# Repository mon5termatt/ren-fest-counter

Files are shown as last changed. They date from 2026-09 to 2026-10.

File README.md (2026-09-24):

# Ren Fest Counter

ESP32-WROOM-32 scoreboards for Renaissance festival games: a name on **8×** MAX7219 8×8 panels and a count on **4×** panels below, with local +/− buttons, a WiZ mote (ESP-NOW), and a SoftAP web UI.

```
  [======== NAME ========]   ← 8 modules (64×8)
  [==== NUMBER ====]         ← 4 modules (32×8), centered
        [ - ]  [ + ]
```

## Features

- Up to **8** scoreboards (compile-time `MAX_COUNTERS`), enable/disable in the web UI
- Each board: 12 FC-16 MAX7219 modules on one SPI chain (zones: name + number)
- Per-board physical **− / +** (debounce + hold-to-repeat); no hardware reset
- **WiZ mote** ESP-NOW remote with web-assignable key → action map
- SoftAP setup UI for names, counts, intensity, remote link, and keymap
- Settings persisted in NVS

## Hardware

### SPI / matrices

Shared `DIN` / `CLK` / **one CS** for the whole name+number daisy-chain. The display always shows the **active** (selected) counter; WiZ 1–4 switches which logical counter is shown.

| Signal | GPIO (default) |
|---|---|
| DIN | 19 |
| CLK | 18 |
| CS | 5 |

Power LED matrices from a solid **5 V** supply (not the ESP32 3V3 pin); share ground with the ESP32.

### Physical buttons

One − / + pair on the board adjusts the **active** counter:

| Button | GPIO |
|---|---|
| − | 26 |
| + | 14 |

Edit all pins in [`include/config.h`](include/config.h). Set unused CS/button entries to `-1`.

For more than ~4 boards you may run out of GPIOs; an I2C expander (e.g. MCP23017) is a later option.

## Build & flash

Requires [PlatformIO](https://platformio.org/).

```bash
pio run                    # build
pio run -e ota -t upload   # HTTP OTA over SoftAP Wi‑Fi (PC must be 192.168.4.x)
pio device monitor         # serial @ 115200
```

OTA uses **Wi‑Fi only** (`ota_host_ip.py` / SoftAP). Upload is an HTTP push to `http://192.168.4.1/update` (also available as a form on the web UI). Password for SoftAP: `renfest123`.

If the device doesn’t have `/update` yet (older build), one USB flash bootstraps it; after that use `-e ota` only.

## Web UI

On boot the ESP32 opens SoftAP:

- SSID: `RenFest-Counter`
- Password: `renfest123`
- URL: http://192.168.4.1/

There you can:

- Edit counter names / counts, enable boards, set LED intensity, blank/unblank
- **Reset counts** (only place that zeros a count — not on the remote or local buttons)
- Link a WiZ remote MAC (or clear to accept any)
- Assign each WiZ key to an action: `none`, `select` (counter N), `inc_active`, `dec_active`, `blank`, `unblank`

## WiZ mote (factory defaults)

Protocol matches WLED’s WiZ remote handler (`WizMoteMessageStructure`).

| Button | Default action |
|---|---|
| 1–4 | Select counter 1–4 |
| Bright + | Increment active |
| Bright − | Decrement active (floor 0) |
| ON | Unblank |
| OFF | Blank (counts kept) |
| NIGHT | Ignored |

Press a key on the remote once so it appears under “Last seen”, then **Link last seen** if you want to lock to that remote.

## Project layout

```
include/config.h       pins, MAX_COUNTERS, AP credentials
src/main.cpp
src/counters.*         state + NVS
src/display.*          MD_Parola zones
src/local_buttons.*    physical +/- 
src/wiz_remote.*       ESP-NOW receive
src/remote_map.*       key → action map
src/web_ui.*           SoftAP HTTP UI
```

## Notes

- ESP-NOW shares the SoftAP Wi-Fi channel (AP starts before ESP-NOW init).
- Module order: if text is mirrored or zones look swapped, check daisy-chain direction / `FC16_HW` vs your PCB variant in `display.cpp`.
- Count range: 0–9999.

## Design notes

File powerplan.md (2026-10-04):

# Ren Fest Counter — Power Plan

Rough runtime estimates for battery operation at a festival day
(**~10 am–9 pm ≈ 11 hours** continuous).

## Measured draws (5 V)

| Condition | Current |
|---|---|
| One half, min brightness | 0.2 A |
| Full setup, min brightness | ~0.4 A (estimated 2× half) |
| Full setup, full brightness (normal content) | 1.1 A |
| Checkerboard test, full bright | 2.0 A |
| All LEDs on, full bright | 3.1 A |

ESP32 / Wi‑Fi overhead is included in these meter readings.

## Power banks

Capacity labels are at **~3.7 V cell** voltage. Usable energy at **5 V USB**
after boost (~85% efficient):

| Bank | Label | Cell energy | ≈ Usable at 5 V |
|---|---|---|---|
| Small | 9000 mAh | ~33 Wh | ~5.6 Ah |
| Baseus Amblight | 30 000 mAh 65 W | **111 Wh** (rated) | ~18.9 Ah |

111 Wh = 30 000 mAh × 3.7 V — same figure the pack claims. At 5 V with ~85%
boost: `111 × 0.85 / 5 ≈ 18.9 Ah`.

[Baseus Amblight 65W 30000mAh](https://www.baseus.com/products/amblight-power-bank-65w-30000mah)

## Runtime estimates

| Load | 9000 mAh | One 30 K (111 Wh) | Two 30 K (sequential) |
|---|---|---|---|
| Full setup, min (0.4 A) | ~14 h | ~47 h | ~94 h |
| Full setup, high (1.1 A) | ~5 h | ~17 h | ~34 h |
| Checkerboard 2.0 A | ~2.8 h | ~9.5 h | ~19 h |
| All-on 3.1 A | ~1.8 h | ~6 h | ~12 h |

Naive “mAh ÷ mA” without the 3.7→5 V conversion overstates runtime by ~1.5–1.6×.

## Festival day (10 am–9 pm)

**11 hours** on one 30 000 mAh bank:

| Brightness | ~Draw | Used in 11 h | Headroom on one 30 K |
|---|---|---|---|
| Min | 0.4 A | ~4.4 Ah | Plenty (~¼ of bank) |
| Medium | 0.8 A | ~8.8 Ah | Comfortable (~½) |
| High | 1.1 A | ~12 Ah | OK (~⅔) |
| All-on stress | 3.1 A | ~34 Ah | **Not viable** on one bank |

## Recommended kit

- **Two Baseus 30 000 mAh** banks on hand.
- **Bank A** — counter only (dedicated cable; don’t share with phone).
- **Bank B** — phone + spare / overnight top-up.

A full phone charge is roughly **10–20 Wh** (~2–4 Ah at 5 V). Bank B can
refill a phone several times and still leave reserve.

## Tips

- Prefer **min–medium brightness** outdoors only as needed; blank/night mode
  when idle.
- Avoid long **all-on / full-bright** test patterns on battery.
- Use a short, thick USB cable; thin cables drop voltage at 1 A+.
- Watch the bank’s overload cutoff if something spikes near 3 A.
- Top up overnight between fest days if running high brightness all day.

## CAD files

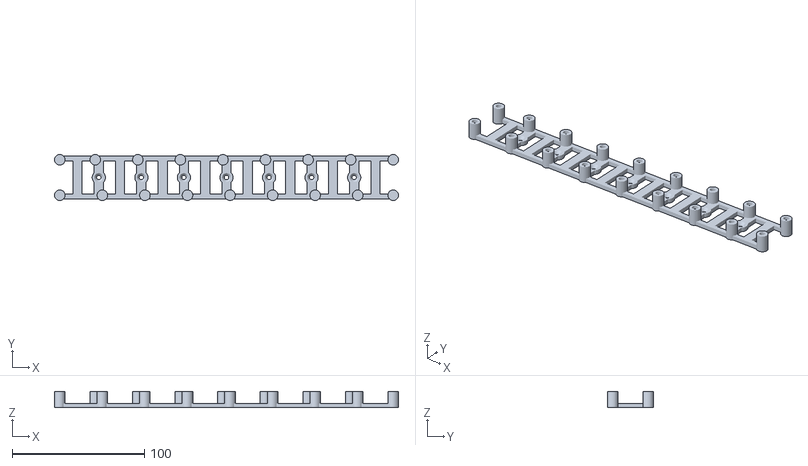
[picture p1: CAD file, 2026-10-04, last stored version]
LED_matrix_revA.stl
259.8 x 34.8 x 12.2

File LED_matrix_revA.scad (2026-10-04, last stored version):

// 8x8 LED matrix mounting frame
// http://www.thingiverse.com/thing:1883325
// Printbus, December 2016
//
// This consists of a mounting frame for 32mm 8x8 LED matrix modules.  
// Revision A adds flexibility that simplifies support for a handful of LED driver
// board types.  Types known to be supported are the FriedCircuits LED Matrix Link v1.2, 
// the printbus/klunkerbus LED Matrix Link v2.0, the board type with a MAXIM MAX7219
// located outside the LED matrix component, and the FC-16 type of driver board.  
// Sample parameters are provided for these boards types.
// 
// The top-level geometry should be tailored for the desired number of modules
// in the x-axis and the number of modules in the y-axis. For reinforcement in long, 
// thin displays, the top level geometry provides for enabling reinforcement struts
// to the x-axis for the inner rows of modules.
//
// For OpenSCAD documentation, see 
// http://en.wikibooks.org/wiki/OpenSCAD_User_Manual/The_OpenSCAD_Language
//
// NOTE ON BOARD ORIENTATIONS: The ability to properly drive pixels throughout an array 
// of modules depends on the board design, board orientation, the software driving the
// display, and the orientation of the LED matrix on the board.  Experimenting with
// a couple of LED modules before finalizing, printing, and assembling/wiring a
// display panel is suggested. 
//
// NOTE ON BOARD DIMENSIONS: The LED matrix components are typically undersized
// slightly less than 32mm. This allows adjacent LED matrices to be spaced at exact
// 32mm intervals so that all LED rows/columns in a large display are equally spaced.
// All of the driver boards sampled, however, have been found to be slightly oversized.
// Although the oversize may be small, it can accumulate and create fit problems for 
// display panels that use a multiple number of adjacent driver boards.  
// The sample dimensions provided here reflect the oversize dimensions measured on
// a small sample of board.  Check the dimensions of your boards for compatibility.
// Note that dimensions may vary across identical boards - don't assume all boards
// will have the same exact dimensions. Adjust the board dimension parameters here
// to accomodate the largest board that will be used.  If there is a concern that
// the oversize boards may lead to undesirable gaps between LED matrices, file the
// board edges as required to allow 32mm intervals and adjust the board dimension
// parameter(s) here accordingly.  
//
// NOTE ON MOUNTING SCREW SIZING: There are multiple factors to consider in choosing the 
// size of screws for mounting driver boards to the printed frame.  1) The amount
// of corner post material provided at each mounting screw location is limited by 
// the space between the board edges and the mounting holes. Using a smaller 
// screw size will increase the corner post wall thickness and provide more strength.  
// 2) Going with a smaller diameter screw provides tolerance in hole placements
// and board alignment.  3) Most boards provide only limited clearance for the
// heads of mounting screws.  A smaller diameter screw will have a smaller
// diameter head.  

// NOTE ON LED MATRIX ALIGNMENT: Sloppy alignment of the LED matrices on the boards can lead to 
// a sloppy looking display panel.   Soldering the LED SIP sockets to the board while 
// the LED matrix is plugged into the SIP sockets is suggested.  
//
// NOTES ON PANEL ASSEMBLY: Especially for larger display panels, measure received 
// driver boards for compatibility with the dimension parameters for the frame design. 
// File or sand material from board edges if boards are excessively oversized.
// Burrs or any other protrusions should be cleaned from the driver boards before 
// mounting them onto the frame.    Install all modules with hardware left initially
// loose, and tighten the hardware after adjusting boards for any alignment issues.
// If multiple smaller frames are used to form a larger display, clean any printing
// burrs from the frame sides that mate.  Zip ties might be adequate in holding partial 
// frames together. 
//
////////// REVISION HISTORY ///////////////////////////////////////////////////
// YYMMDD date code
// 161110 - initial publish
// 161203 - Revision A, improved support for additional board types

////////// INCLUDE AND USE  ///////////////////////////////////////////////////
// NOTE: openSCAD version 2014.03 or newer recommended

////////// TOP LEVEL GEOMETRY  ////////////////////////////////////////////////
// Array size and options are set in PARAMETERS below (x_count, y_count, strut)
frame( x_count=x_count, y_count=y_count, strut=strut );

////////// PARAMETERS  ////////////////////////////////////////////////////////
// All dimensions are millimeter
// Open Window > Customizer to edit these as UI controls

/* [Frame] */
// Number of LED modules in the x-axis
x_count = 8;
// Number of LED modules in the y-axis
y_count = 2;
// X-axis reinforcement struts between y-axis rows
strut = false;

/* [LED Posts] */
// Fastener type in corner posts
post_fastener = "heatset"; // [heatset:M3 heat-set insert, thread:M3 direct thread (self-tap)]
// Which corners get screw posts
post_mode = "skip"; // [diagonal:Diagonal (FL+RR), every_other:Every other column, skip:Skip X (outer of group)]
// Skip mode: physical board width in modules (e.g. 4 for 4-wide FC-16 style)
post_group_x = 4; // [1:16]
// Skip mode: physical board height in modules
post_group_y = 1; // [1:8]
// Skip mode: which side to keep at board-board seams (holes are too close for both)
post_seam = "keep_right"; // [keep_right:Keep right (skip next board left), keep_left:Keep left (skip prev board right)]
// Heat-set: recommended hole ID for typical M3 brass inserts (mm)
post_insert_id = 4.0;
// Heat-set: insert length / blind hole depth (mm)
post_insert_depth = 5.0;
// Heat-set: minimum post OD for wall strength around the insert (mm)
post_od_min = 8.0;
// Direct thread: hole ID for M3 self-tap into plastic (nominal 2.7 + print fit)
post_thread_id = 2.9;
// Fragment count for round posts and holes
fn_circle = 64; // [16:128]

/* [Panel Mount] */
// Enable frame-to-board mounting holes between modules
panel_mount = true;
// Clearance hole ID — M3 standard fit (mm)
mnt_hid = 3.3;
// Countersink OD at frame front (mm)
mnt_cs_od = 6.5;
// Countersink depth (mm)
mnt_cs_depth = 2.0;
// Circular pad OD at each mount point (mm)
mnt_pad_od = 10;

/* [Hidden] */
// Board Reference Dimensions (as measured)
// Sample measurements are provided for various module types
// Only one block of measurements should be uncommented - all others need to be commented out
// Tailor the measurements for your board type if your measurements differ
// -------- dimensions for Friedcircuits LED Matrix Link v1.2 and LED Matrix Master v1.2
// For Friedcircuits v1.2, see https://friedcircuits.us/
// Note that Friedcircuits hole spacing leaves limited room for screw heads
// If using right angle headers to interconnect boards, consider soldering them after mounting boards
//   This will help minimize header placement from affecting board spacing
/*  ( a /* here comments out this block, a //* will uncomment it )
bd_sx = 32.2;       // board size in x-axis for the LED module
bd_sy = 32.25;      // board size in y-axis for the LED module
bd_hspx = 27.8;     // board hole spacing in x-axis, center to center
bd_hspy = 27.8;     // board hole spacing in y-axis, center to center
bd_hid = 3.3;       // board hole inner diameter (not used, but included for reference)
bd_pin_len = 0;     // pcb pin length in area of I-frame strut (n/a for low if_strut_w values)
//*/

// -------- dimensions for LED Matrix Link, klunkerbus v2.0
// For klunkerbus v2.0, see https://oshpark.com/shared_projects/J1PUJCGP
// If using right angle headers to interconnect boards, consider soldering them after mounting boards
//   This will help minimize header placement from affecting board spacing
//*  ( a /* here comments out this block, a //* will uncomment it )
bd_sx = 32.15;      // board size in x-axis for the LED module
bd_sy = 32.15;      // board size in y-axis for the LED module
bd_hspx = 26.8;     // board hole spacing in x-axis, center to center
bd_hspy = 26.8;     // board hole spacing in y-axis, center to center
bd_hid = 3.3;       // board hole inner diameter (not used, but included for reference)
bd_pin_len = 0;     // pcb pin length in area of I-frame strut (n/a for low if_strut_w values)
//*/
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

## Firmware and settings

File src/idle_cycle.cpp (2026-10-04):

#include "idle_cycle.h"
#include "config.h"
#include "counters.h"
#include "display.h"
#include "setup_menu.h"

namespace {
  uint32_t lastActivityMs = 0;
  uint32_t lastCycleMs = 0;
  bool cycling = false;
  bool idleOwnsScroller = false;
  bool waitScrollerPass = false;  // hold until marquee finishes one pass (if scrolling)
  uint8_t playlistCursor = 0;  // next step to show
  uint8_t msgCursor = 0;       // next auto message index
  uint8_t cntCursor = 0;       // next auto counter index
  uint8_t prevOut = 0;         // effectOut of the step currently on screen

  int8_t nextEnabled(uint8_t from) {
    for (uint8_t step = 1; step <= MAX_COUNTERS; step++) {
      uint8_t i = (from + step) % MAX_COUNTERS;
      if (Counters::isEnabled(i)) return static_cast<int8_t>(i);
    }
    return -1;
  }

  int8_t nextEnabledFrom(uint8_t from) {
    for (uint8_t step = 0; step < MAX_COUNTERS; step++) {
      uint8_t i = (from + step) % MAX_COUNTERS;
      if (Counters::isEnabled(i)) return static_cast<int8_t>(i);
    }
    return -1;
  }

  int8_t nextMessageFrom(uint8_t from) {
    const uint8_t n = Counters::scrollMessageCount();
    if (n == 0) return -1;
    for (uint8_t step = 0; step < n; step++) {
      uint8_t i = (from + step) % n;
      const char* msg = Counters::scrollMessage(i);
      if (msg && msg[0]) return static_cast<int8_t>(i);
    }
    return -1;
  }

  uint8_t enabledTotal() {
    return Counters::enabledCount();
  }

  bool anyNonEmptyMessage() {
    return nextMessageFrom(0) >= 0;
  }

  bool stepIsValid(const IdleStep& step) {
    if (step.kind == IdleCounter) {
      if (step.index == IdleAutoIndex) return enabledTotal() > 0;
      return Counters::isEnabled(step.index);
    }
    if (step.kind == IdleMessage) {
      if (step.index == IdleAutoIndex) return anyNonEmptyMessage();
      if (step.index >= Counters::scrollMessageCount()) return false;
      const char* msg = Counters::scrollMessage(step.index);
      return msg && msg[0];
    }
    return false;
  }

  int8_t nextValidPlaylistIndex(uint8_t from) {
    const uint8_t len = Counters::idlePlaylistLen();
    if (len == 0) return -1;
    for (uint8_t step = 0; step < len; step++) {
      uint8_t i = (from + step) % len;
      if (stepIsValid(Counters::idleStep(i))) return static_cast<int8_t>(i);
    }
    return -1;
  }

  void stopIdleScroller() {
    if (idleOwnsScroller) {
      idleOwnsScroller = false;
      waitScrollerPass = false;
      if (Display::scrollerActive()) {
        Display::stopManualScroller(false);
      }
    }
  }

  // out(prev) → in(next); caller stamps hold after this returns.
  bool showPlaylistStep(uint8_t idx) {
    IdleStep step = Counters::idleStep(idx);
    if (!stepIsValid(step)) return false;
    const uint8_t effectIn = step.effectIn;
    const uint8_t effectOut = step.effectOut;
    const uint8_t exitEff = prevOut;

    if (step.kind == IdleCounter) {
      uint8_t ci = step.index;
      if (ci == IdleAutoIndex) {
        int8_t n = nextEnabledFrom(cntCursor);
        if (n < 0) return false;
        ci = static_cast<uint8_t>(n);
        cntCursor = static_cast<uint8_t>((ci + 1) % MAX_COUNTERS);
      }
      // Don't hard-clear — snapshot must see current pixels for the out anim.
      if (idleOwnsScroller) {
        idleOwnsScroller = false;
        waitScrollerPass = false;
      }
      Display::animateDisplayedOff(exitEff);
      Counters::setActiveIndex(ci, false);
      Display::idleShowNext(Counters::getConst(ci).count, effectIn);
      prevOut = effectOut;
      return true;
    }

    // Message: startManualScroller snapshots + exit-animates with prevOut.
    uint8_t mi = step.index;
    if (mi == IdleAutoIndex) {
      int8_t n = nextMessageFrom(msgCursor);
      if (n < 0) return false;
      mi = static_cast<uint8_t>(n);
      const uint8_t msgN = Counters::scrollMessageCount();
      msgCursor = msgN ? static_cast<uint8_t>((mi + 1) % msgN) : 0;
    }
    idleOwnsScroller = false;
    waitScrollerPass = false;
    const char* msg = Counters::scrollMessage(mi);
    Display::startManualScroller(effectIn, msg, Counters::scrollMessageBottom(mi), exitEff);
    idleOwnsScroller = Display::scrollerActive();
    // Only wait for a full pass when text actually scrolls (fit-only).
    waitScrollerPass = idleOwnsScroller && !Display::scrollerCompletedPass();
    prevOut = effectOut;
    return true;
  }

  bool advanceLegacyCounters() {
    int8_t n = nextEnabled(Counters::activeIndex());
    if (n < 0) return false;
    if (idleOwnsScroller) {
      idleOwnsScroller = false;
      waitScrollerPass = false;
    }
    Display::animateDisplayedOff(prevOut);
    Counters::setActiveIndex(static_cast<uint8_t>(n), false);
    Display::idleShowNext(Counters::getConst(n).count, Counters::idleEffectIn());
    prevOut = Counters::idleEffectOut();
    return true;
  }

  bool advanceOnce() {
    const uint8_t len = Counters::idlePlaylistLen();
    if (len == 0) {
      return advanceLegacyCounters();
    }

    int8_t idx = nextValidPlaylistIndex(playlistCursor);
    if (idx < 0) return false;
    if (!showPlaylistStep(static_cast<uint8_t>(idx))) return false;
    playlistCursor = static_cast<uint8_t>((static_cast<uint8_t>(idx) + 1) % len);
    return true;
  }

  bool holdElapsed(uint32_t now) {
    // Scrolling messages: advance as soon as one full marquee pass finishes.
    if (waitScrollerPass) {
      if (Display::scrollerActive() && !Display::scrollerCompletedPass()) return false;
      waitScrollerPass = false;
      return true;
    }
    // Counters / static (fit) messages: hold for idle cycle seconds.
    const uint32_t holdMs = (uint32_t)Counters::idleCycleSeconds() * 1000UL;
    return (now - lastCycleMs) >= holdMs;
  }
}

namespace IdleCycle {

void begin() {
  lastActivityMs = millis();
  lastCycleMs = millis();
  cycling = false;
  idleOwnsScroller = false;
  waitScrollerPass = false;
  playlistCursor = 0;
  msgCursor = 0;
  cntCursor = 0;
  prevOut = Counters::idleEffectOut();
}

void noteActivity() {
  lastActivityMs = millis();
  if (cycling) {
    cycling = false;
    stopIdleScroller();
    Serial.println(F("[idle] activity — stop cycle"));
  }
}

bool isCycling() { return cycling; }

bool startNow() {
  const uint8_t plLen = Counters::idlePlaylistLen();
  if (plLen == 0 && enabledTotal() < 2) return false;
  if (plLen > 0 && nextValidPlaylistIndex(0) < 0) return false;
  if (Counters::blanked() && Counters::blankBrightnessPercent() == 0) return false;

  // Drop any idle-owned marquee before restarting from the top.
  stopIdleScroller();
  cycling = true;
  playlistCursor = 0;
  msgCursor = 0;
  cntCursor = 0;
  waitScrollerPass = false;
  prevOut = Counters::idleEffectOut();
  Serial.println(F("[idle] start now"));
  if (!advanceOnce()) {
    cycling = false;
    return false;
  }
  lastCycleMs = millis();
  lastActivityMs = millis();
  return true;
}

void loop() {
  if (SetupMenu::active()) return;

  if (Display::scrollerActive() && !idleOwnsScroller) {
    return;
  }

  const uint8_t plLen = Counters::idlePlaylistLen();
  if (plLen == 0 && enabledTotal() < 2) {
    cycling = false;
    return;
  }
  if (plLen > 0 && nextValidPlaylistIndex(0) < 0) {
    cycling = false;
    return;
  }

  if (Counters::blanked() && Counters::blankBrightnessPercent() == 0) {
    return;
  }

  const uint32_t now = millis();

  if (!cycling) {
    if (now - lastActivityMs >= (uint32_t)Counters::idleTimeoutSeconds() * 1000UL) {
      cycling = true;
      playlistCursor = 0;
      msgCursor = 0;
      cntCursor = 0;
      waitScrollerPass = false;
      prevOut = Counters::idleEffectOut();
      Serial.println(F("[idle] start cycle"));
      if (!advanceOnce()) {
        cycling = false;
      } else {
        // Hold starts after enter finishes (advanceOnce is blocking on anims).
        lastCycleMs = millis();
      }
    }
    return;
  }

  if (!holdElapsed(now)) return;

  if (!advanceOnce()) {
    cycling = false;
    stopIdleScroller();
  } else {
    lastCycleMs = millis();
  }
}

}  // namespace IdleCycle

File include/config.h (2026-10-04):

#pragma once

#include <Arduino.h>

// ---------------------------------------------------------------------------
// Single scoreboard: one CS daisy-chain (name panels + number panels).
// Remote 1–4 / web switches which logical counter is shown on that display.
// ---------------------------------------------------------------------------
static constexpr bool SINGLE_DISPLAY = true;

// Full build: NAME=8, NUMBER=4 on one daisy-chain.
static constexpr uint8_t MODULES_NAME = 8;
static constexpr uint8_t MODULES_NUMBER = 4;
static constexpr uint8_t MODULES_PER_BOARD = MODULES_NAME + MODULES_NUMBER;

// 8×2 frame: top (name) row is rotated 180° relative to the number row.
static constexpr bool NAME_ZONE_FLIP_UD = true;
static constexpr bool NAME_ZONE_FLIP_LR = true;

static constexpr uint8_t MAX_COUNTERS = 8;
static constexpr uint8_t NAME_MAX_LEN = 15;
static constexpr int32_t COUNT_MAX = 9999;

// ---------------------------------------------------------------------------
// SPI / MAX7219 — one CS for the whole name+number chain
// ---------------------------------------------------------------------------
#if defined(ARDUINO_XIAO_ESP32C3)
// XIAO ESP32C3 — SPI on D7/D8/D10 edge (D9 left free / BOOT); VCC/GND on their own pads
static constexpr uint8_t PIN_DIN = 10;     // D10
static constexpr uint8_t PIN_CLK = 8;      // D8
static constexpr int8_t PIN_CS = 20;       // D7
#else
// ESP32-WROOM-32 defaults
static constexpr uint8_t PIN_DIN = 19;
static constexpr uint8_t PIN_CLK = 18;
static constexpr int8_t PIN_CS = 5;
#endif

// Kept as arrays for compatibility; only [0] is used in SINGLE_DISPLAY mode.
static constexpr int8_t CS_PINS[MAX_COUNTERS] = {
  PIN_CS, -1, -1, -1, -1, -1, -1, -1
};

#include "wifi_config.h"

static constexpr uint8_t DEFAULT_INTENSITY = 4;
static constexpr uint8_t DEFAULT_ENABLED_COUNT = 4;  // slots 1–4 selectable out of the box
static constexpr uint8_t SCROLLER_MAX_LEN = 64;      // top marquee message
static constexpr uint8_t SCROLLER_BOTTOM_MAX_LEN = 16; // bottom line (number zone)
static constexpr uint8_t MAX_SCROLL_MESSAGES = 8;
static constexpr uint8_t MAX_IDLE_PLAYLIST = 16;

// ---------------------------------------------------------------------------
// Idle auto-cycle (single display)
// ---------------------------------------------------------------------------
static constexpr uint32_t IDLE_TIMEOUT_MS = 30000;  // start cycling after 30s idle
static constexpr uint32_t IDLE_CYCLE_MS = 5000;     // default; override via web UI idleCycleSeconds
static constexpr uint16_t DOUBLE_TAP_MS = 400;      // WiZ remote double-tap window

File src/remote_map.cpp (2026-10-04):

#include "remote_map.h"
#include "config.h"
#include "counters.h"
#include "display.h"
#include "idle_cycle.h"
#include "setup_menu.h"
#include "show_mode.h"
#include <Preferences.h>
#include <cstring>

namespace {
  Preferences prefs;

  constexpr uint8_t WIZ_ON = 1;
  constexpr uint8_t WIZ_OFF = 2;
  constexpr uint8_t WIZ_NIGHT = 3;
  constexpr uint8_t WIZ_BRIGHT_DOWN = 8;
  constexpr uint8_t WIZ_BRIGHT_UP = 9;
  constexpr uint8_t WIZ_ONE = 16;
  constexpr uint8_t WIZ_TWO = 17;
  constexpr uint8_t WIZ_THREE = 18;
  constexpr uint8_t WIZ_FOUR = 19;

  constexpr uint8_t KNOWN_BUTTONS[] = {
    WIZ_ON, WIZ_OFF, WIZ_NIGHT,
    WIZ_BRIGHT_DOWN, WIZ_BRIGHT_UP,
    WIZ_ONE, WIZ_TWO, WIZ_THREE, WIZ_FOUR
  };
  constexpr uint8_t KNOWN_COUNT = sizeof(KNOWN_BUTTONS) / sizeof(KNOWN_BUTTONS[0]);

  RemoteMap::Binding bindings[KNOWN_COUNT];

  // ON×3 then OFF×3 (≤1.5s between taps) opens setup.
  // First ON unblanks immediately; further taps only advance the combo.
  constexpr uint8_t COMBO_NEED = 3;
  constexpr uint32_t COMBO_GAP_MS = 1500;
  uint8_t comboOnCount = 0;
  uint8_t comboOffCount = 0;
  uint32_t comboLastMs = 0;
  bool comboActive = false;
  bool comboOnFired = false;  // first ON already ran UNBLANK

  void clearComboArm() {
    comboOnCount = 0;
    comboOffCount = 0;
    comboActive = false;
    comboOnFired = false;
  }

  int findIndex(uint8_t buttonId);  // defined below

  void execute(uint8_t action, uint8_t param, uint8_t effectIn, uint8_t effectOut,
               uint8_t speed);  // defined below

  void fireBindingIndex(int idx) {
    if (idx < 0 || idx >= static_cast<int>(KNOWN_COUNT)) return;
    const RemoteMap::Binding& b = bindings[idx];
    if (b.action != RemoteMap::ACTION_IDLE_START) {
      IdleCycle::noteActivity();
    }
    execute(b.action, b.param, b.effectIn, b.effectOut, b.speed);
  }

  int findIndex(uint8_t buttonId) {
    for (uint8_t i = 0; i < KNOWN_COUNT; i++) {
      if (bindings[i].buttonId == buttonId) return i;
    }
    return -1;
  }

  uint8_t clampEffect(uint8_t e) {
    return ShowMode::valid(e) ? e : ShowMode::LEFT;
  }

  uint8_t clampSpeed(uint8_t s) {
    if (s == 0) return 0;  // 0 = use anim-type default
    if (s > 20) return 20;
    return s;
  }

  void setDefault(uint8_t id, uint8_t act, uint8_t param,
                  uint8_t effectIn, uint8_t effectOut = ShowMode::LEFT,
                  uint8_t speed = 0) {
    for (uint8_t i = 0; i < KNOWN_COUNT; i++) {
      if (bindings[i].buttonId == id) {
        bindings[i].action = act;
        bindings[i].param = param;
        bindings[i].effectIn = effectIn;
        bindings[i].effectOut = effectOut;
        bindings[i].speed = speed;
        return;
      }
    }
  }

  void applyDefaults() {
    for (uint8_t i = 0; i < KNOWN_COUNT; i++) {
      bindings[i].buttonId = KNOWN_BUTTONS[i];
      bindings[i].action = RemoteMap::ACTION_NONE;
      bindings[i].param = 0;
      bindings[i].effectIn = ShowMode::LEFT;
      bindings[i].effectOut = ShowMode::LEFT;
      bindings[i].speed = 0;
    }

    setDefault(WIZ_ONE, RemoteMap::ACTION_SELECT, 0, ShowMode::LEFT, ShowMode::LEFT);
    setDefault(WIZ_TWO, RemoteMap::ACTION_SELECT, 1, ShowMode::LEFT, ShowMode::LEFT);
    setDefault(WIZ_THREE, RemoteMap::ACTION_SELECT, 2, ShowMode::LEFT, ShowMode::LEFT);
    setDefault(WIZ_FOUR, RemoteMap::ACTION_SELECT, 3, ShowMode::LEFT, ShowMode::LEFT);
    setDefault(WIZ_BRIGHT_UP, RemoteMap::ACTION_INC_ACTIVE, 0, ShowMode::UP, ShowMode::LEFT);
    setDefault(WIZ_BRIGHT_DOWN, RemoteMap::ACTION_DEC_ACTIVE, 0, ShowMode::DOWN, ShowMode::LEFT);
    setDefault(WIZ_ON, RemoteMap::ACTION_UNBLANK, 0, ShowMode::FREEZE, ShowMode::FREEZE);
    setDefault(WIZ_OFF, RemoteMap::ACTION_BLANK, 0, ShowMode::FREEZE, ShowMode::FREEZE);
    setDefault(WIZ_NIGHT, RemoteMap::ACTION_SCROLLER, 0, ShowMode::LEFT, ShowMode::LEFT);
  }

  void execute(uint8_t action, uint8_t param, uint8_t effectIn, uint8_t effectOut,
               uint8_t speed) {
    const uint8_t inEff = clampEffect(effectIn);
    const uint8_t outEff = clampEffect(effectOut);
    const uint8_t spd = clampSpeed(speed);

    if (action != RemoteMap::ACTION_SCROLLER && Display::scrollerActive()) {
      // Animate marquee off with this key's out, then continue the action.
      Display::animateDisplayedOff(outEff, spd);
      Display::stopManualScroller(action != RemoteMap::ACTION_SELECT);
    }

    switch (action) {
      case RemoteMap::ACTION_NONE:
        break;

      case RemoteMap::ACTION_SELECT:
        if (Counters::isEnabled(param)) {
          Counters::setActiveIndex(param);
          Display::selectShow(inEff, spd);
          Counters::saveIfDirty();
          Serial.printf("[wiz] select counter %u (%s) in %u out %u spd %u\n", param + 1,
                        Counters::getConst(param).name, inEff, outEff, spd);
        } else {
          Serial.printf("[wiz] select %u ignored (disabled)\n", param + 1);
        }
        break;

      case RemoteMap::ACTION_INC_ACTIVE: {
        uint8_t a = Counters::activeIndex();
        if (Counters::inc(a)) {
          Display::onCountIncreased(Counters::getConst(a).count, inEff, spd);
          Counters::saveIfDirty();
        }
        break;
      }

      case RemoteMap::ACTION_DEC_ACTIVE: {
        uint8_t a = Counters::activeIndex();
        if (Counters::dec(a)) {
          Display::onCountDecreased(Counters::getConst(a).count, inEff, spd);
          Counters::saveIfDirty();
        }
        break;
      }

      case RemoteMap::ACTION_BLANK:
        Counters::setBlanked(true);
        Display::applyBlanked();
        Counters::saveIfDirty();
        break;

      case RemoteMap::ACTION_UNBLANK:
        Counters::setBlanked(false);
        Display::applyBlanked();
        Counters::saveIfDirty();
        break;

      case RemoteMap::ACTION_SCROLLER:
        IdleCycle::noteActivity();
        if (Display::scrollerActive()) {
          Display::animateDisplayedOff(outEff, spd);
          Display::stopManualScroller();
          Serial.println(F("[wiz] scroller stop"));
        } else {
          Display::startManualScroller(inEff, nullptr, nullptr, outEff, spd);
          Serial.println(F("[wiz] scroller start"));
        }
        break;

      case RemoteMap::ACTION_IDLE_START:
        if (IdleCycle::isCycling()) {
          IdleCycle::noteActivity();
          Serial.println(F("[wiz] idle stop"));
        } else if (IdleCycle::startNow()) {
          Serial.println(F("[wiz] idle start"));
        } else {
          Serial.println(F("[wiz] idle start failed"));
        }
        break;

      default:
        break;
    }
  }
}

namespace RemoteMap {

void factoryDefaults() {
  applyDefaults();
}

void begin() {
  applyDefaults();
  load();
}

void loop() {
  if (!comboActive) return;
  if (static_cast<uint32_t>(millis() - comboLastMs) < COMBO_GAP_MS) return;
  // Sequence timed out — first ON already unblanked; just drop the arm.
  clearComboArm();
}
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

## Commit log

2026-09-24 Initial commit: Ren Fest Counter ESP32 scoreboard with SoftAP/STA, OTA, and scroller
2026-10-04 Single-display support, new web UI, and more.
    [LED_matrix_revA.scad, LED_matrix_revA.stl]
2026-10-04 Add festival battery power plan from measured draws.
2026-10-04 More Stuff.
    [LED_matrix_revA.scad, LED_matrix_revA.stl]
